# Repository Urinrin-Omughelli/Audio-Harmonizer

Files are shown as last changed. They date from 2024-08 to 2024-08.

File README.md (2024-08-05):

# Audio Harmonizer 
# 1.	Executive Summary
The Audio Harmonizer is a product that will revolutionize solo performances by introducing an affordable and easy to use system. Users can generate or build a series of harmonies through a mobile application which is used alongside a microphone and harmony generator to output multiple harmonies through a speaker in real time. The product utilizes signal manipulation to create harmonies from the user’s own voice. By combining converters, microcontrollers, and a mobile application, our team will create a system that produces a choir effect that can only be replicated by multiple pre-recorded voices. The following sections walk through a high level overview of the system as well as information regarding its use, users, and impact.

# 2.	Introduction
The system will be composed of a blackbox with audio input and output that connects to a mobile application via bluetooth to generate harmonies in real time. The system will be capable of generating harmonies for a variety of chord progressions at any tempo as well as allowing composers to create their own harmonies on the mobile app. Users such as solo independent artists and those without the proper money or resources for proper equipment can use our application to create more complex art easily.

# 2.1. Background
With a rise in accessibility of producing and creating music, artists have been known to rise to stardom via free applications one can find on their phone such as Soundcloud, Tiktok, or Youtube. By creating technology that allows people to create music from their bedrooms, the music industry has transformed allowing those without the proper funding or resources a fair chance at success. Our team has come up with a product that will allow even the most inexperienced musicians to bring complexity and artistry to their work in a way that previously was far more exclusive.
The audio harmonizer is an application that creates a four part harmony in real time. By connecting the necessary equipment to your phone via bluetooth, the mobile app allows you to have control over what harmonies you wish to add or create from scratch. Simply connect a microphone to the input and a speaker to the output on the equipment, pick the mode of operation and either use the automated harmonies or create your own, choose the volume settings for each harmony, and set the speed of the song. Now, when you sing or play into the microphone, an output of up to four melodies will be heard as the lead melody is being played.
Existing plugins that create harmonies do exist, however, most of the harmonizers can create only two  or three harmonies. In addition the more complex harmonizers are very expensive, costing up to $250 to use outside of a two week free trial. The plugins also only work with digital audio workstations (DAW). Good quality DAW can cost anywhere from $60 - $1000, which could be another cost that a small up and coming musician cannot afford. By making an affordable four part harmonizer that also can exist as a stand alone application, we are ensuring that independent artists can use our product to compose, produce, and perform.

The Audio Harmonizer system comprises two major components, the mobile application and the harmony generator, as seen in Figure 2.1. The mobile application that allows the users to choose the harmonies and the tempo of the music. This information will be passed via bluetooth to the harmony generator.  
The harmony generator takes an analog audio input from a microphone, converts it to a digital signal, uses the information passed down via bluetooth to generate the correct harmonies, and converts the new digital signal to an analog output which can be played through an amplifier.

Figure 1.1. Manual Mode Input-Output Diagram


Figure 1.2. Automatic Mode Input-Output Diagram

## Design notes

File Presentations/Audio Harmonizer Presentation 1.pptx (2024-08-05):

## Audio Harmonizer

Urinrinoghene Lauretta Omughelli and Team

## Project Statement

Create a system that allows artists to create multiple harmonies in real time for performances.

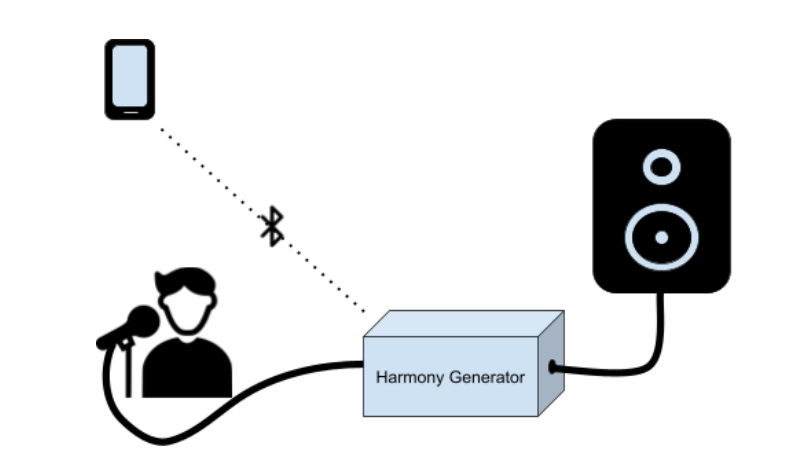
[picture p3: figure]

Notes: Jason

## Project Subsystems

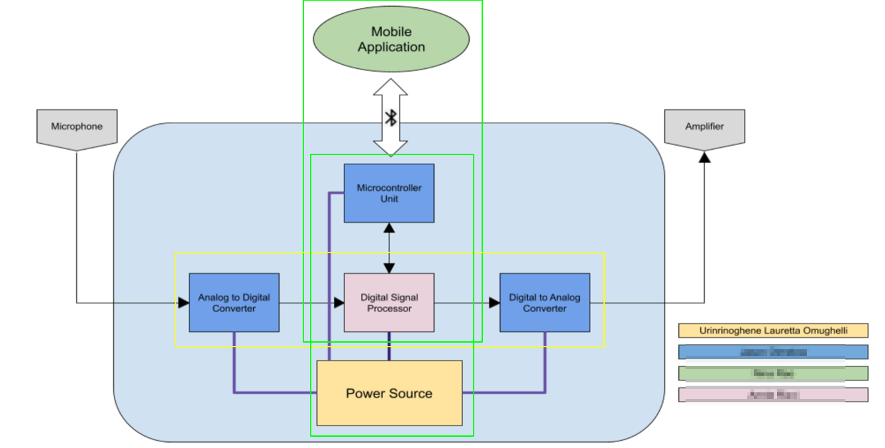
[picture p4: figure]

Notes: Nina:

## Major Changes

- DSP Hardware Switched to Real Time MCU
- No recording option due to time constraints
  - Originally an optional addition

## Project Current Timeline

- Integrating DSP Algorithms on to Real-Time MCU with Audio Booster Pack
- MCU and Android Application Bluetooth Communication
- Power PCB Order

## Subsystems

## Subsystem 1: Digital Signal Processor

Accomplishments Since 403 <20 hrs> | Ongoing progress/problems and plans until next presentation
Chose replacement Real-Time MCU for DSP subsystem | Running TI Sample Project Refactoring Sample Project for Harmonizing Algorithms Receive user input from MCU

## Digital Signal Processor

- MSP430 Real-Time MCU with BOOSTXL-AUDIO Pack
- TI Sample Project
  - Records for 3 seconds, plays for 3 seconds
  - Refactor to play and record in real time (with slight delay)
  - Insert algorithms from ECEN 403
- Set up code to take user input from MCU

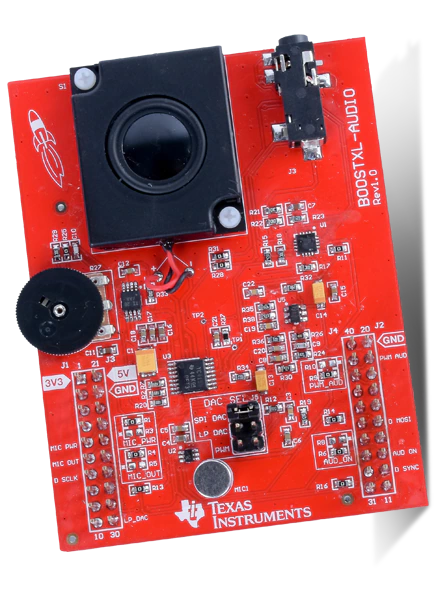
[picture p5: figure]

## Subsystem 2: Microcontroller Unit

Accomplishments Since 403 <30 hrs> | Ongoing progress/problems and plans
MCU Testing from last semester complete In process of Bluetooth integration | Communication with App via bluetooth Communication with Battery Fuel Gauge Communication with DSP

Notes: MCU will be relaying data to and fro the dsp/user interface via bluetooth. Telling the DSP what type of harmony the user wants, and then sending the digital to back to the app...

## Subsystem 3: Converters/Main Unit Schematic

Accomplishments Since 403 <5 Hrs> | Ongoing progress/problems and plans until next presentation
Have a physical PCB design from last semester that is now impractical for our use | Waiting for DSP hardware testing and selection to finish PCB manufacturing for DSP/MCU PCB unit

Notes: 24 bits is the optimal bitrate as 32 is unnecessary, 48kHz for HiFi audio, minimum is 40kHz for good audio quality

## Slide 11

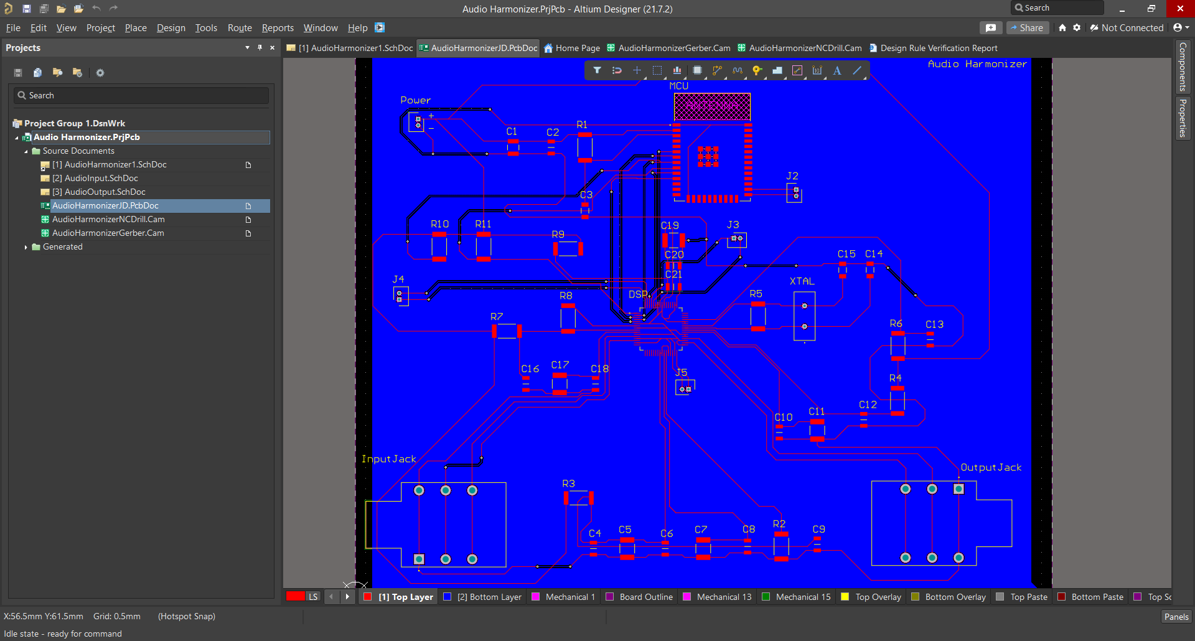
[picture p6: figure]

## Subsystem 4: Android Application

Accomplishments Since 403 <10 hrs> | Ongoing progress/problems and plans until next presentation
Application is ready to send data from automatic and manual mode Able to pair application to the ESP32 | Connect Android and ESP32 to send data

## Subsystem 5: Power Supply Urinrinoghene Lauretta Omughelli

Accomplishments Since 403 <60 hrs> | Ongoing progress/problems and plans until next presentation
Designed battery charger, fuel gauge and converter IC breakout boards for perf board testing Test and validation Modified schematic to fix low/unstable output voltage Completed PCB design revision | I2C programming of fuel gauge IC Test PCB and check output voltage

## Power Supply Urinrinoghene Lauretta omughelli

What currently works (On Perf board)?
-Battery charger IC charges battery
-Converter input voltage correctly switches between charger IC and battery
-Constant current when battery is charging
What doesn’t work?
-Low/unstable output voltage at buck-boost converter
What is changing?
- 1 buck boost converter

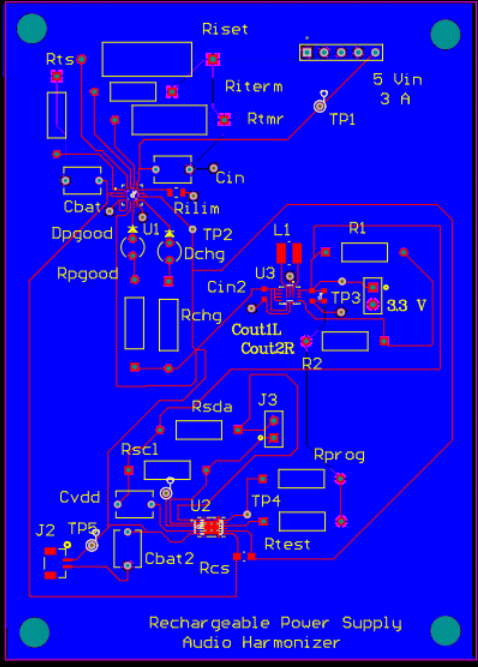
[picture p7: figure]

Updated PCB Design

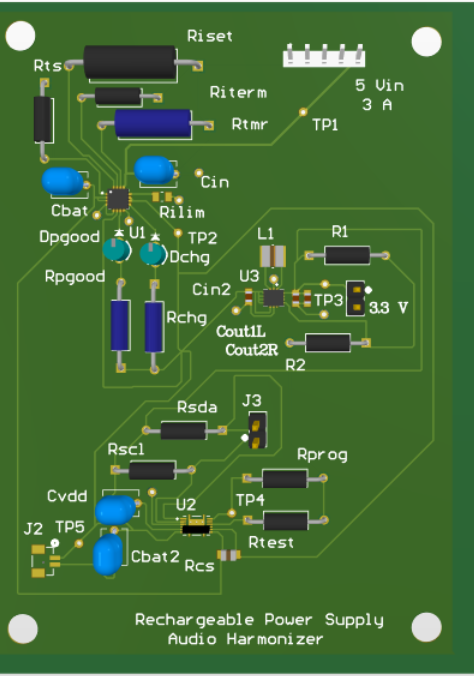
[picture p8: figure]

## Progress

## Parts Ordering Status

- All parts necessary for Power already ordered and received
- Power PCB Ordered
- MCU and DSP Ordered
- Order ADC/DAC that match TI DSP Launchpad
- Main PCB (MCU, DSP, ADC/DAC) will be ordered by next update

## Execution Plan

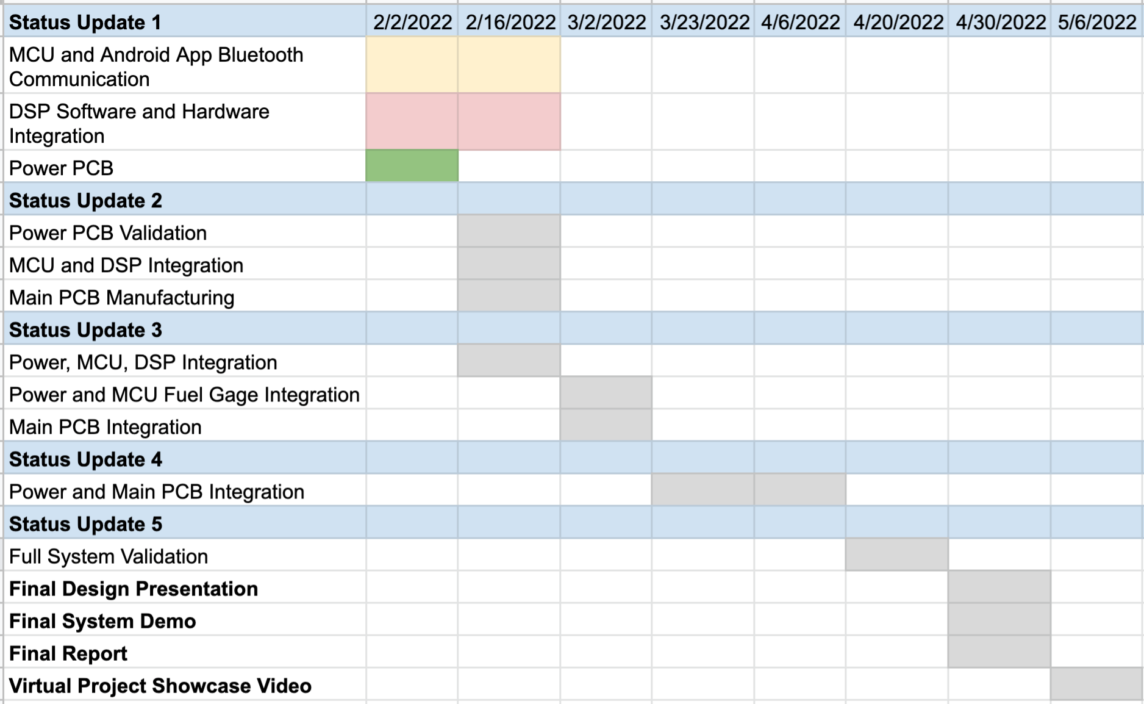
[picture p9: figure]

## Questions?

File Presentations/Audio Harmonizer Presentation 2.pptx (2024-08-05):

## Audio Harmonizer

Urinrinoghene Lauretta Omughelli and Team

## Project Statement

Create a system that allows artists to create multiple harmonies in real time for performances.


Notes: Jason

## Project Subsystems


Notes: Nina:

## Project Current Timeline

- Integrating DSP Algorithms on to Real-Time MCU
- MCU and Android Application Bluetooth Communication Complete
- Fuel Gauge Integration in Progress

## Subsystems

## Completed Subsystems

- Android Application
- Power Supply
- MCU

## Subsystem 1: Digital Signal Processor

Accomplishments Since 403 <30 hrs> | Ongoing progress/problems and plans until next presentation
Connected with TI Support Sample Project Running Two different avenues available Codec Interrupt Code | Process audio in and Out in Real Time Integrate Harmonies Receive user input from MCU

## Digital Signal Processor

- Electric Guitar Capo Capstone Project
  - Codec Functions
  - Project Code Mimics Existing Algorithm
- TI Sample Project
  - Waiting for TI Support
- Set up code to take user input from MCU


## Subsystem 2: Microcontroller Unit

Accomplishments Since 403 <25 hrs> | Ongoing progress/problems and plans
MCU Testing from last semester complete Communication with App via bluetooth Working on I2C communication with Battery Fuel Gauge | Communication with DSP

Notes: MCU will be relaying data to and fro the dsp/user interface via bluetooth. Telling the DSP what type of harmony the user wants, and then sending the digital to back to the app...

## Automatic Mode

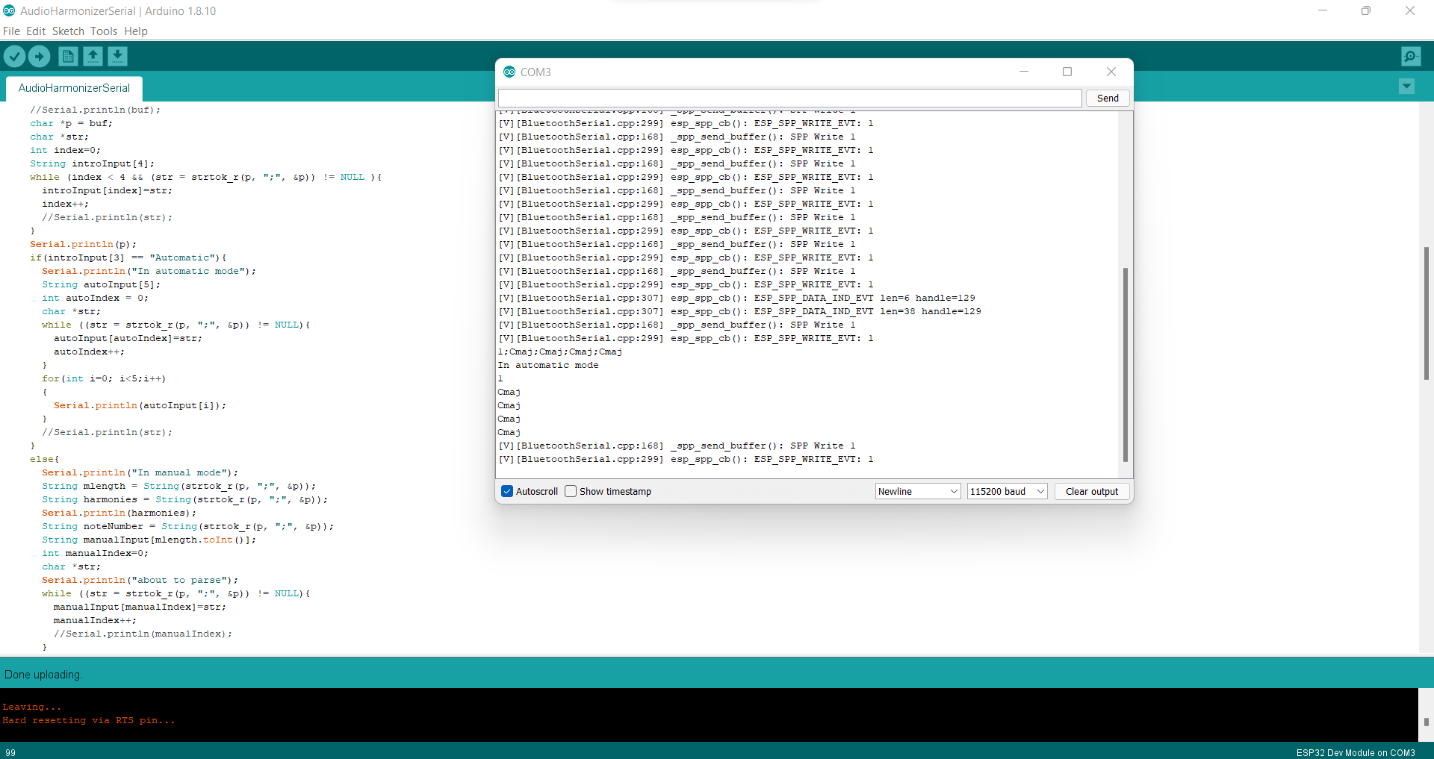
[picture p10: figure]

## Manual Mode

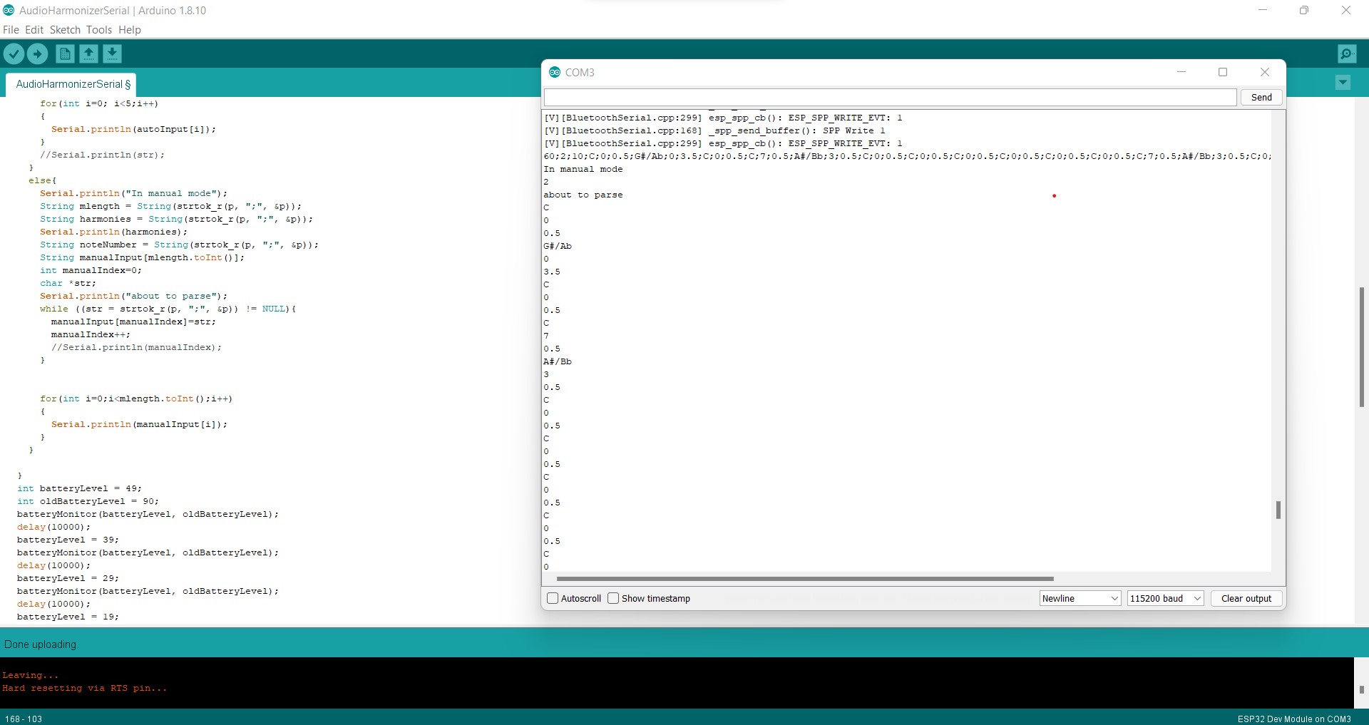
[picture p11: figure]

## Subsystem 3: Converters/Main Unit Schematic

Accomplishments Since 403 <0 Hrs> | Ongoing progress/problems and plans until next presentation
Have a physical PCB design from last semester that is now impractical for our use | Waiting for DSP hardware testing and selection to finish PCB manufacturing for DSP/MCU PCB unit

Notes: 24 bits is the optimal bitrate as 32 is unnecessary, 48kHz for HiFi audio, minimum is 40kHz for good audio quality

## Subsystem 4: Android Application

Accomplishments Since Last Presentation <25 hrs> | Ongoing progress/problems and plans until next presentation
Working bluetooth communication between ESP32 and Android App Interpret Data from app for the DSP Fixed styling issues | Display battery levels on the app

## Subsystem 5: Power Supply Urinrinoghene Lauretta Omughelli

Accomplishments Since Our Last Presentation <12 hrs> | Ongoing progress/problems and plans until next presentation
Ordered and Received PCB Worked on fuel gauge I2C programming in preparation for Integrating with MCU subsystem | PCB assembly, test, and validate 3.3 V at the output of the converter Test I2C communication with ESP 32

## Fuel Gauge Reading

- Arduino Library for BQ27411
  - Should work with BQ27441
- Arduino Code written to read I2C data for:
  - State of charge
  - Voltage
  - Current
- Re-test once parts are completely soldered

Lauretta & Annie

## Bluetooth Communication

- MCU and Android App Connect via Bluetooth
- Android App able to send user inputs as string
- MCU Arduino Code able to receive and interpret user input into corresponding variables for manual and automatic modes

Jason & Nina

## Progress

## Parts Ordering Status

- Main PCB needs to be designed and ordered

## Execution Plan

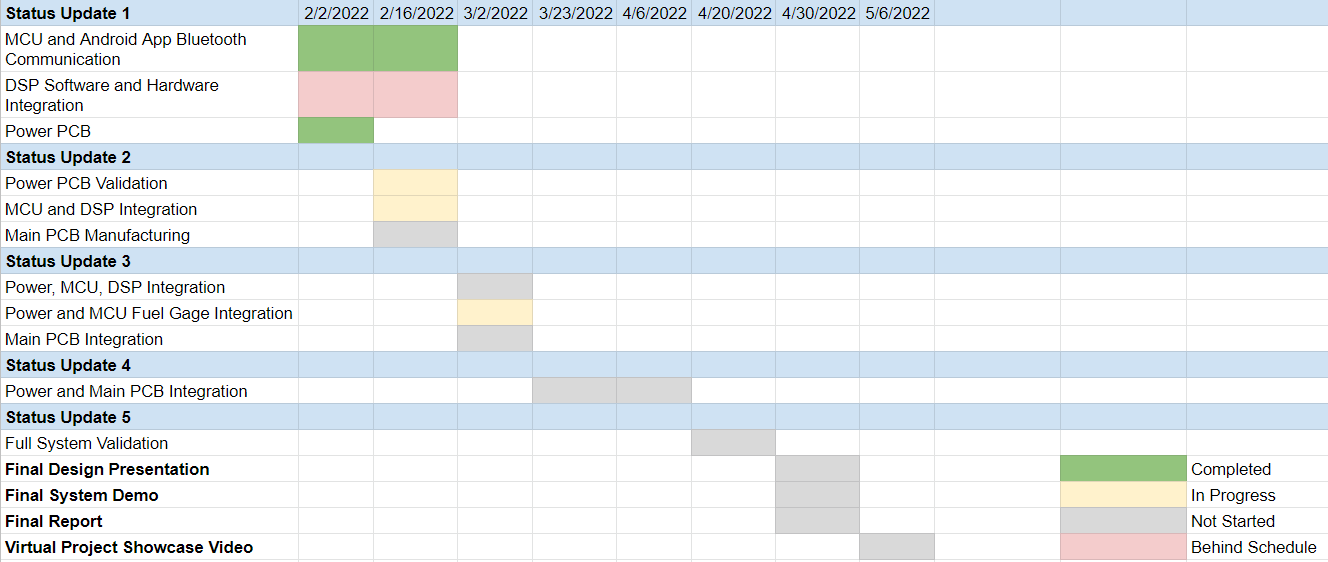
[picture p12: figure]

## Questions?

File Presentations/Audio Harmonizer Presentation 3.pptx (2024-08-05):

## Audio Harmonizer

Urinrinoghene Lauretta Omughelli and Team

## Project Statement

Create a system that allows artists to create multiple harmonies in real time for performances.


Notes: Jason

## Project Subsystems


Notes: Nina:

## Project Current Timeline

- Integrating DSP Algorithms on to Real-Time MCU
- MCU and Android Application Bluetooth Communication Complete
- Fuel Gauge Integration in Progress
- Main PCB Design in Progress
- Power Supply PCB Reordered

## Subsystem 1: Digital Signal Processor

Accomplishments Since Last Presentation <45 hrs> | Ongoing progress/problems and plans until next presentation
Met with TI Support Refactored project | Complete refactoring Integrate Harmonies Receive user input from MCU

## Digital Signal Processor

- 2 DMA Channels taking Audio input in ping-pong format
- Timer set to 20kHz for ADC and DAC input/output
- Close to completing continuous audio record and playback
- Meeting with TI Support set for tomorrow


## Microcontroller Unit Main Unit Schematic/PCB

Accomplishments Since Last Presentation <5 hrs> | Ongoing progress/problems and plans
MCU Testing from last semester complete Communication with App via bluetooth working fully | Communication with DSP Working on I2C communication with Battery Fuel Gauge

Accomplishments Since Last Presentation <15 Hrs> | Ongoing progress/problems and plans until next presentation
Soldered most of old design PCB | Will be attempting redesign with new MSP430 chip for audio in/out

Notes: MCU will be relaying data to and fro the dsp/user interface via bluetooth. Telling the DSP what type of harmony the user wants, and then sending the digital to back to the app...

## PCB Design

- Need to add missing capacitors
- Likely will redesign with MSP430

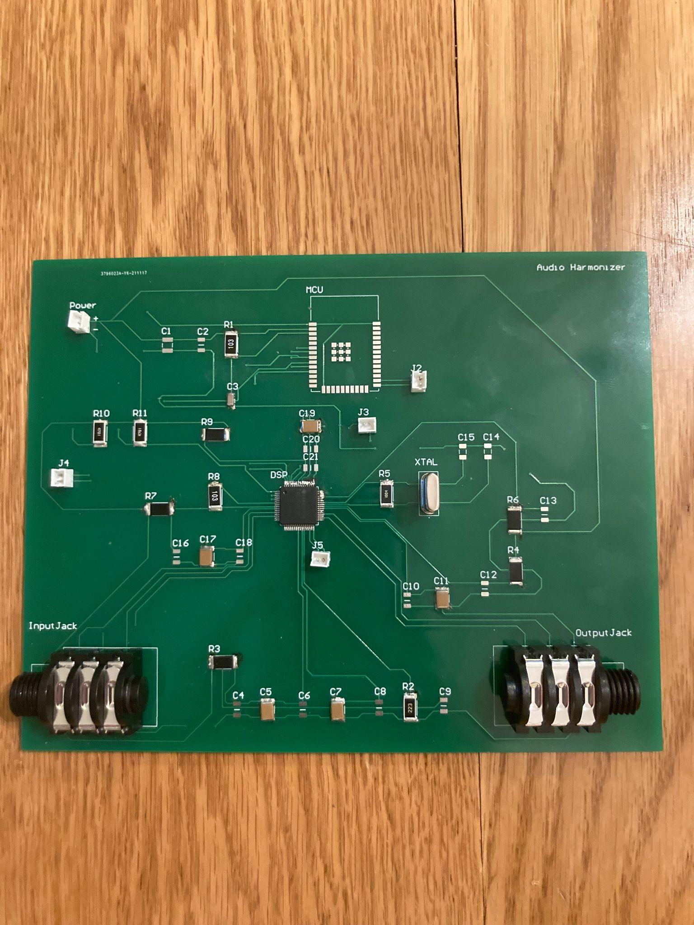
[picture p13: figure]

## Power Supply and Integration with MCU I2C Communication

Accomplishments Since Our Last Presentation <10 hrs> | Ongoing progress/problems and plans until next presentation
Tested PCB functionality Fuel gauge I2C programming for Integrating with MCU subsystem | PCB short circuit issue due to clearance rule violation being diabled in Altium Issue resolved and PCB reordered Test I2C communication with ESP 32

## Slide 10

Power Supply PCB

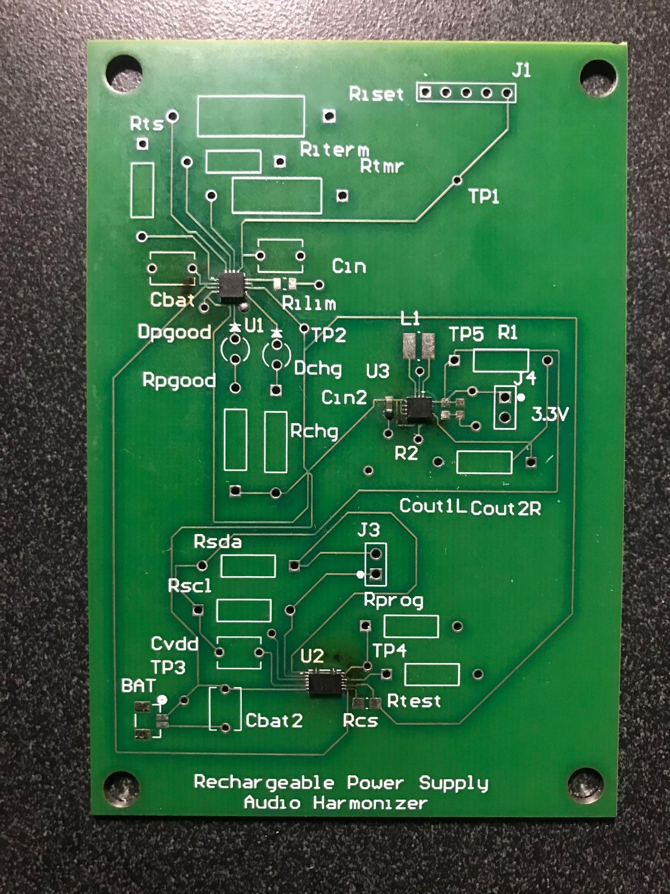
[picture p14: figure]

## Fuel Gauge Reading

- Arduino Library for BQ27411
  - Should work with BQ27441
- Arduino Code written to read I2C data for:
  - State of charge
  - Voltage
  - Current
- Re-test once parts are completely soldered

Lauretta & Annie

## Bluetooth Communication

- MCU and Android App Connect via Bluetooth
- Android App able to send user inputs as string
- MCU Arduino Code able to receive and interpret user input into corresponding variables for manual and automatic modes
- Android App is able to receive battery level from the MCU and display it accordingly

Jason & Nina

## Parts Ordering Status

- Main PCB needs to be ordered

## Progress

## Execution Plan

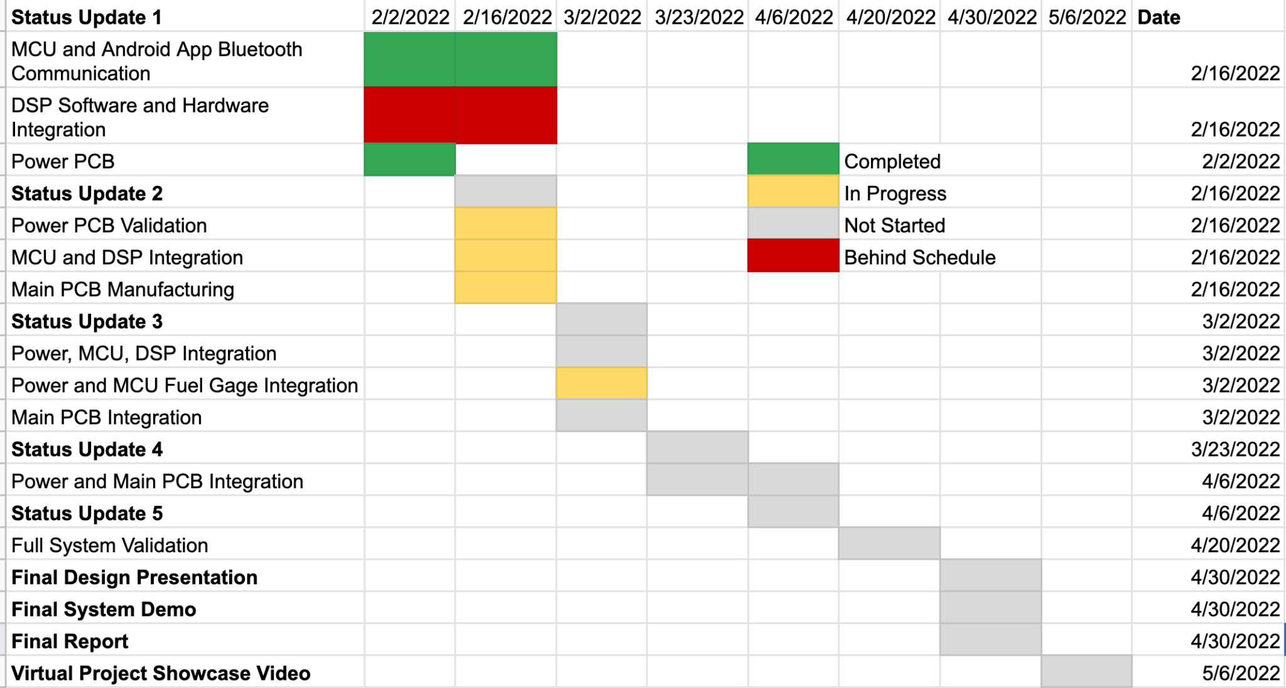
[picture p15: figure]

## Questions?

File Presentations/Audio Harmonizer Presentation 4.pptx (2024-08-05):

## Audio Harmonizer

Urinrinoghene Lauretta Omughelli and Team

## Project Statement

Create a system that allows artists to create multiple harmonies in real time for performances.


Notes: Jason

## Project Subsystems


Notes: Nina:

## Project Current Timeline

- Real-Time Audio Functioning
- MCU and Android Application Bluetooth Communication Integrated and Validated
- Fuel Gage Integrated (Not Validated)
- MCU and DSP I2C Communication Integrated and Validated
- Power Supply Integrated (Not Validated)

## Digital Signal Processor

Accomplishments Since Last Presentation <35 hrs> | Ongoing progress/problems and plans until next presentation
MSP430 Launchpad and ADC/DAC integration complete Audio working in Real-Time I2C Communication with MCU Integrated and Validated | Use IQMATHLIB for Hamonizing Algorithm and FFTs in MSP430

## I2C MCU and DSP Integration

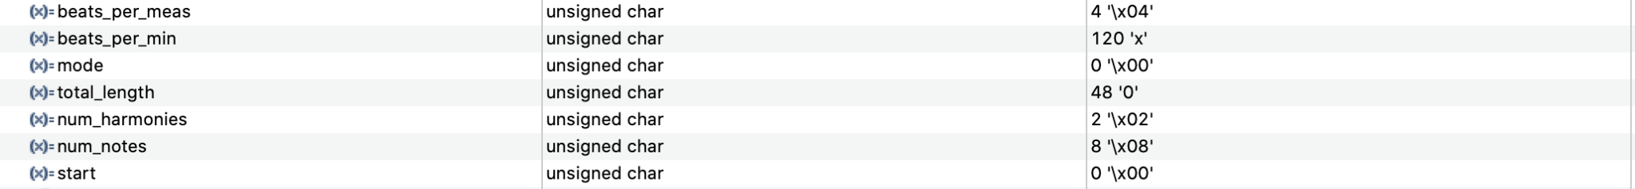
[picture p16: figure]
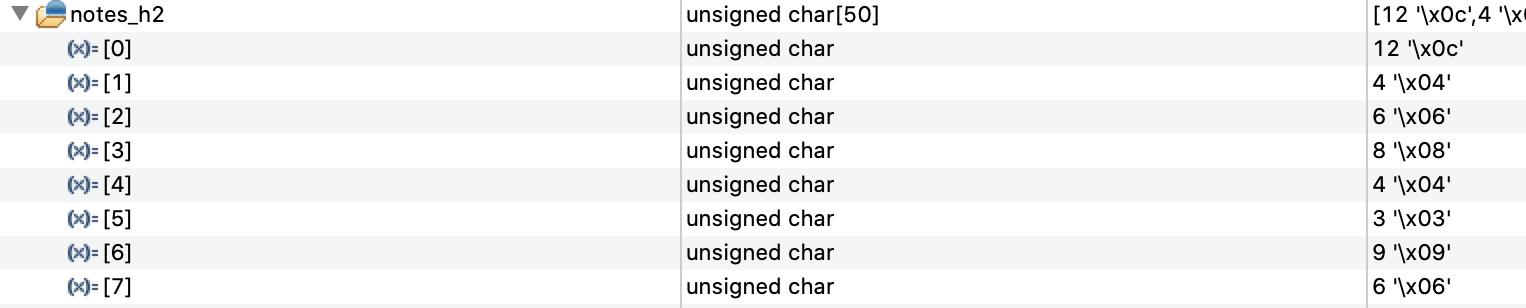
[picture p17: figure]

## Microcontroller Unit Main Unit Schematic/PCB

Accomplishments Since Last Presentation <~ hrs> | Ongoing progress/problems and plans
Integrated With all Other Systems

Accomplishments Since Last Presentation <30 Hrs> | Ongoing progress/problems and plans until next presentation
PCB and Parts Ordered | Solder and Test

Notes: MCU will be relaying data to and fro the dsp/user interface via bluetooth. Telling the DSP what type of harmony the user wants, and then sending the digital to back to the app...

## Schematics

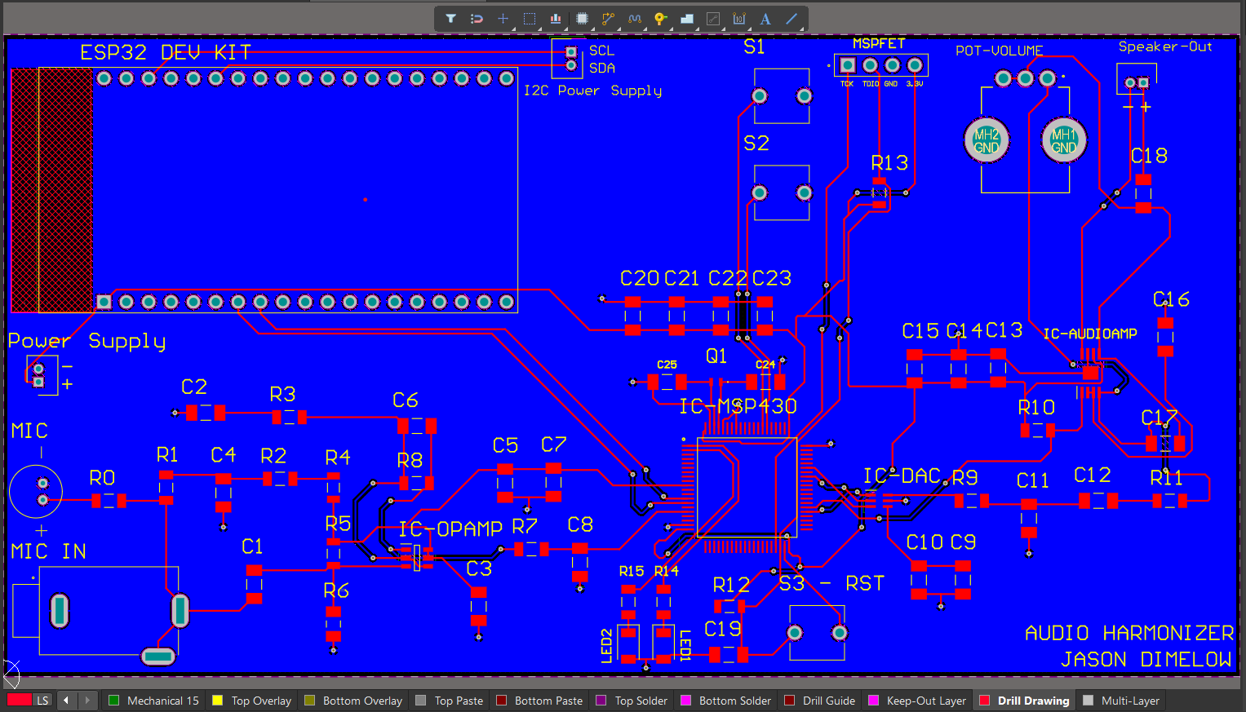
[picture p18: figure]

## Power Supply and Integration with MCU I2C Communication

Accomplishments Since Our Last Presentation <20 hrs> | Ongoing progress/problems and plans until next presentation
Tested PCB functionality Tested charger IC Fixed output voltage issue I2C communication between fuel gauge and MCU complete (reads state of charge, battery voltage, and capacitance) | Validate state of charge (%) reading of fuel gauge

## Fuel Gauge Integration

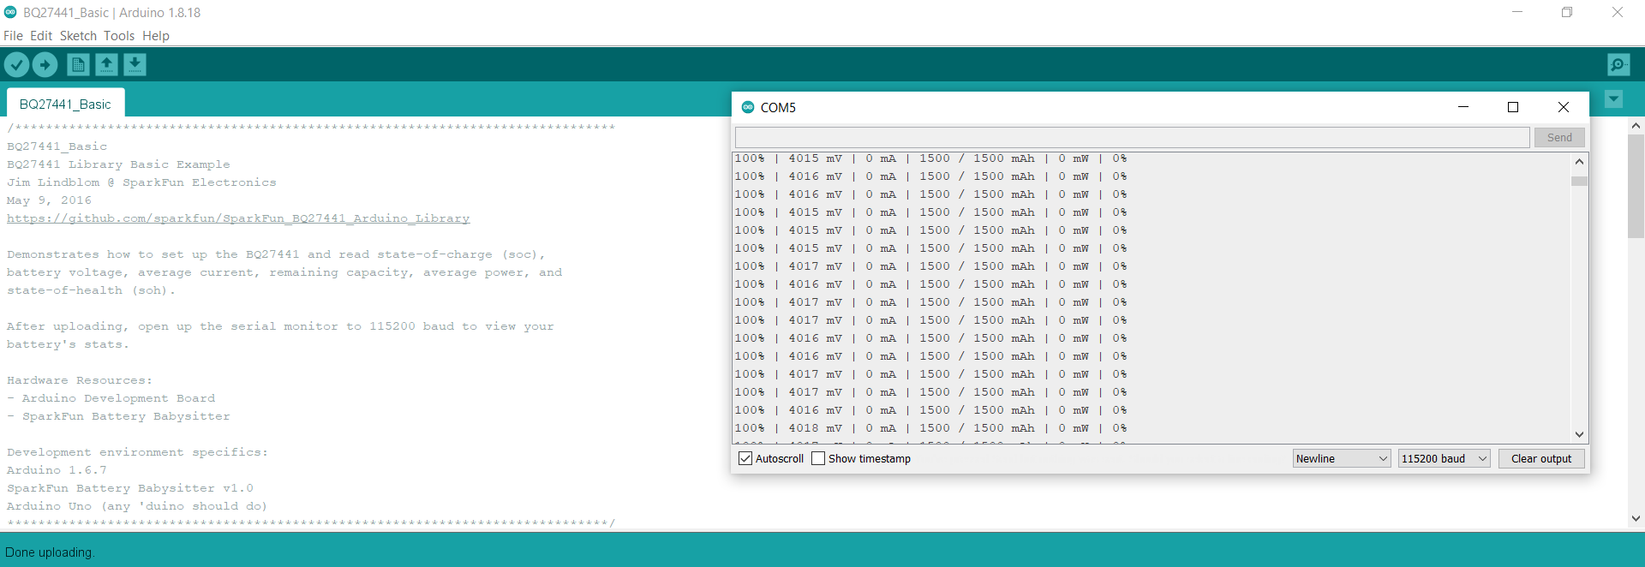
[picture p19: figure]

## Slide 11

Power Supply Validation

Dchg LED is low impedance when battery is disconnected

Dchg LED is high Impedance when battery is connected

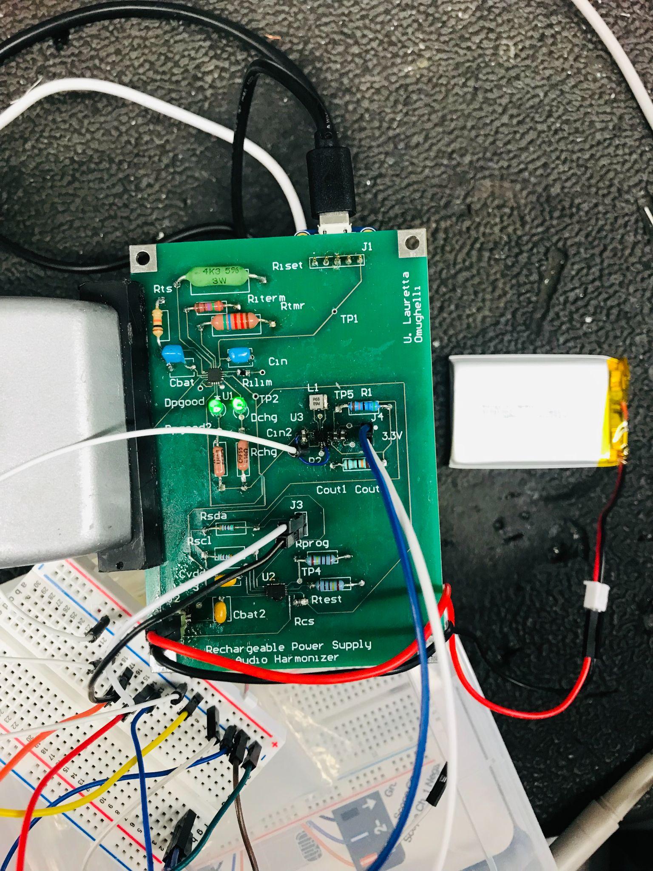
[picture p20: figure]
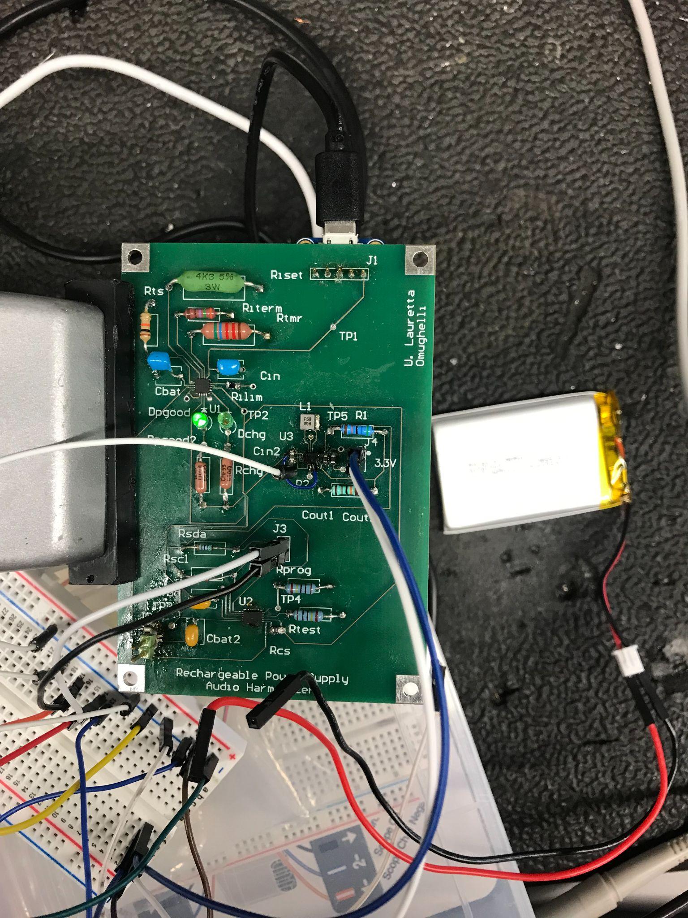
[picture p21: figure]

Shows that battery is disconnected/not charging

Shows that battery is charging

-LED on the left is always on to indicate that a valid input source is received

## Power Supply Waveform

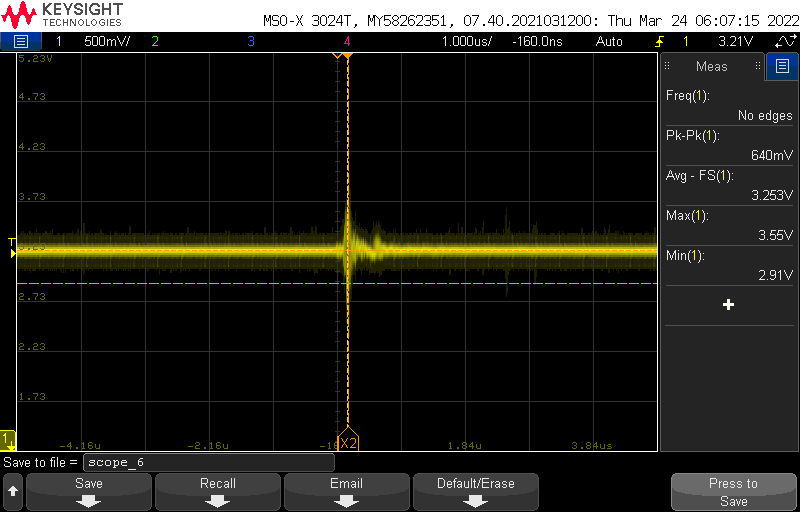
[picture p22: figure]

-Output voltage varies between 3.25-3.36V

## Power Supply Integration

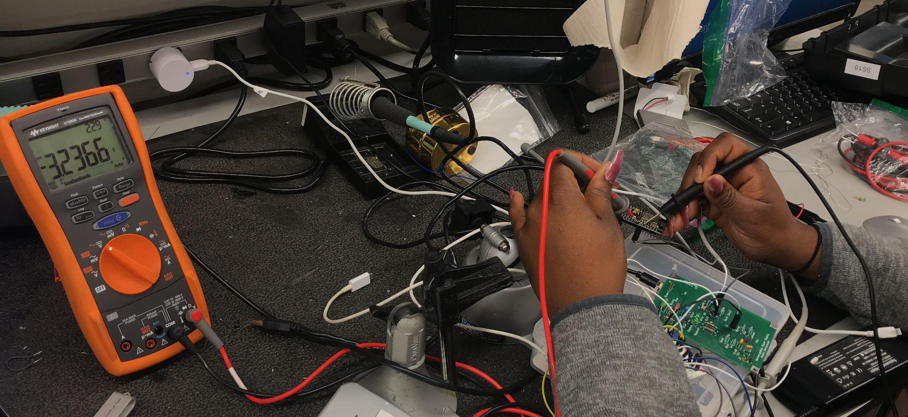
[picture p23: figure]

## Android App

Accomplishments Since Last Presentation <20 hrs> | Ongoing progress/problems and plans until next presentation
Error Handling Worked on Styling | Continue validating and integrating with full system

## Before & After

Bluetooth Page

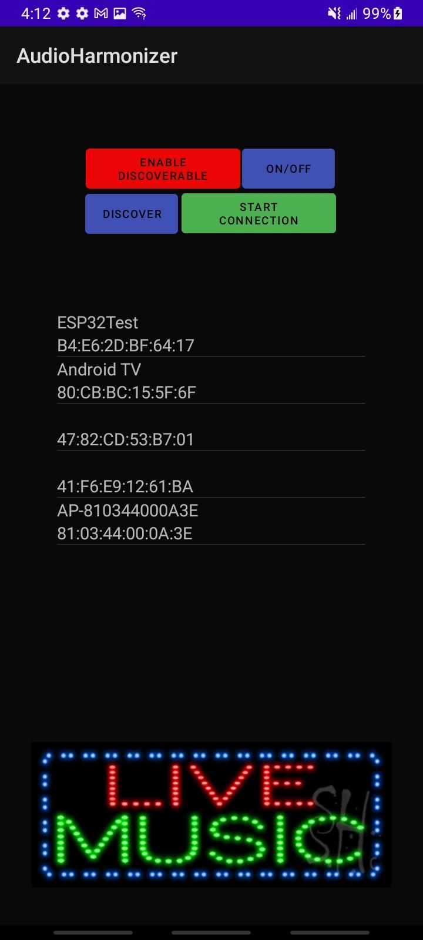
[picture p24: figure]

Initial Input Page

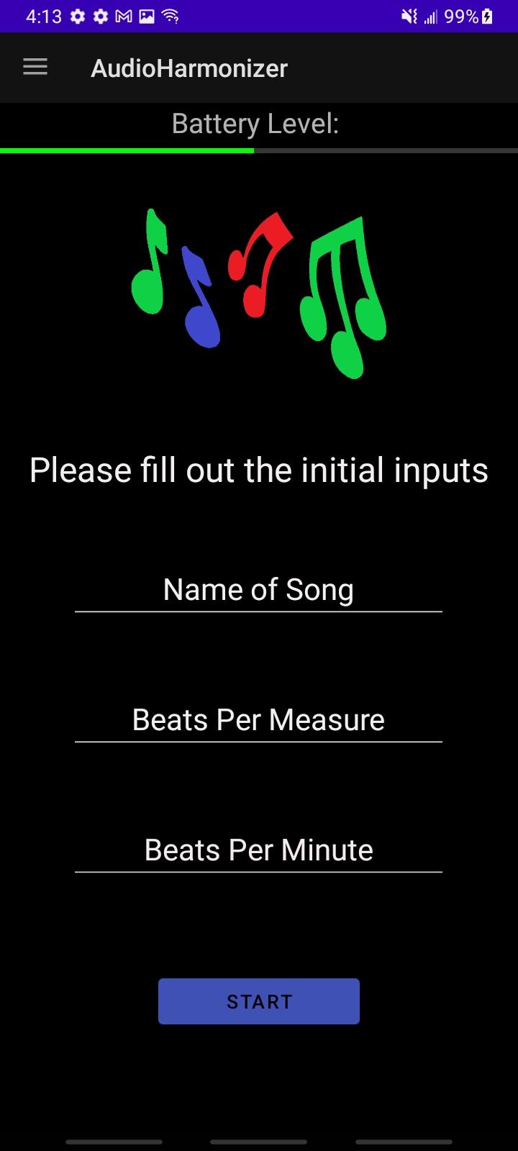
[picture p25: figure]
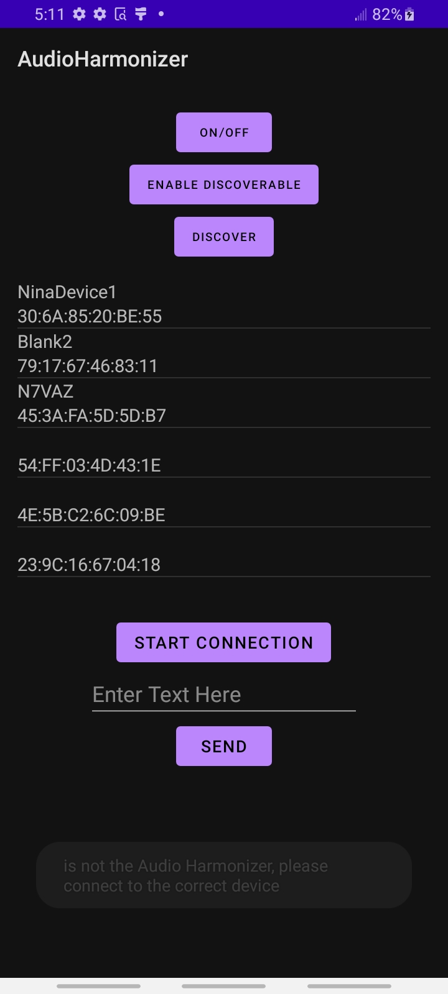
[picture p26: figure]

## Before & After


Automatic Page


Start Singing Page


## Progress

## Execution Plan


## Questions?

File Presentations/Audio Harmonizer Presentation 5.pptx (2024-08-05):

## Audio Harmonizer

Urinrinoghene Lauretta Omughelli and Team

## Project Statement

Create a system that allows artists to create multiple harmonies in real time for performances.


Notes: Jason

## Project Subsystems


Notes: Nina:

## Project Current Timeline

- Real-Time Audio Functioning
- MCU and Android Application Bluetooth Communication Integrated and Validated
- MCU and DSP I2C Communication Integrated and Validated
- Power Supply Integrated and Validated

## Digital Signal Processor

Accomplishments Since Last Presentation <18 hrs> | Ongoing progress/problems and plans until next presentation
Integrated IQMATHLIB into MSP430 Project Refactored parts of algorithm program into Code Composer Studio | Finish integrating algorithms and validate (non-real time version) Reattempt algorithm with complex DSK Kit for real-time functionality*

## Microcontroller Unit Main Unit Schematic/PCB

Accomplishments Since Last Presentation <3 hrs> | Ongoing progress/problems and plans
Seamless communication between Fuel Gauge, MCU, and Android App

Accomplishments Since Last Presentation <25 Hrs> | Ongoing progress/problems and plans until next presentation
Schematic Completed and Ordered | MSP430 Flash Hardware Solder parts

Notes: MCU will be relaying data to and fro the dsp/user interface via bluetooth. Telling the DSP what type of harmony the user wants, and then sending the digital to back to the app...

## Schematics


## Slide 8


## Power Supply Integration with MCU and Android App

Accomplishments Since Our Last Presentation <20 hrs> | Ongoing progress/problems and plans until next presentation
Successfully Integrated power supply with DSP (MSP430) and MCU (ESP32) Successfully Integrated fuel gauge with MCU/App | Validate battery percentage on App Output voltage starts at 2.6 V before reaching 3.3 V- Use linear regulator to fix 2.6 V output

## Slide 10

Power Supply Output Voltage Validation with DSP and MCU


## Android App

Accomplishments Since Last Presentation <20 hrs> | Ongoing progress/problems and plans until next presentation
Implemented new method for receiving battery level | Android App is complete

## Progress

## Execution Plan


## Questions?

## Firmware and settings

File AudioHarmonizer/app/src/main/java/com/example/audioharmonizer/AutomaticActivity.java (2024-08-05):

package com.example.audioharmonizer;

import androidx.annotation.NonNull;
import androidx.annotation.RequiresApi;
import androidx.appcompat.app.ActionBarDrawerToggle;
import androidx.appcompat.app.AppCompatActivity;
import androidx.drawerlayout.widget.DrawerLayout;

import android.Manifest;
import android.bluetooth.BluetoothAdapter;
import android.bluetooth.BluetoothDevice;
import android.bluetooth.BluetoothSocket;
import android.content.BroadcastReceiver;
import android.content.Context;
import android.content.Intent;
import android.content.IntentFilter;
import android.content.pm.PackageManager;
import android.content.pm.ResolveInfo;
import android.content.res.ColorStateList;
import android.graphics.Color;
import android.net.Uri;
import android.os.Build;
import android.os.Bundle;
import android.os.Environment;
import android.os.Handler;
import android.util.Log;
import android.view.MenuItem;
import android.view.View;
import android.widget.AdapterView;
import android.widget.ArrayAdapter;
import android.widget.Button;
import android.widget.EditText;
import android.widget.ListView;
import android.widget.ProgressBar;
import android.widget.Spinner;
import android.widget.Toast;

import com.google.android.material.navigation.NavigationView;

import java.io.File;
import java.io.IOException;
import java.io.InputStream;
import java.nio.charset.Charset;
import java.util.ArrayList;
import java.util.List;
import java.util.UUID;

public class AutomaticActivity extends AppCompatActivity implements NavigationView.OnNavigationItemSelectedListener{

    Button automatic_finish_button;//send button

    private static final String TAG = "AutomaticActivity";

    BluetoothDevice mBTDevice;
    BluetoothAdapter mBlueAdapter;
    //public ArrayList<BluetoothDevice> mBTDevices = new ArrayList<>();

    public DrawerLayout drawerLayout_automatic;
    public ActionBarDrawerToggle actionBarDrawerToggle_automatic;
    private NavigationView navigationView;
    public String delim = ";";

    private Handler handler = new Handler();
    int batteryLevel = 0;
    ProgressBar progress;


    @Override
    protected void onCreate(Bundle savedInstanceState) {
        super.onCreate(savedInstanceState);
        setContentView(R.layout.activity_automatic);

        final GlobalClass globalVariable = (GlobalClass) getApplicationContext();

        //**********************************bluetooth***************************************


        mBlueAdapter = BluetoothAdapter.getDefaultAdapter();
        if(!mBlueAdapter.isEnabled()){
            showToast("You must turn bluetooth back on");
            Intent intent = new Intent(AutomaticActivity.this, Bluetooth2Activity.class);
            startActivity(intent);
        }


        //**********************************bluetooth***************************************



        //**********************NavBar Functionality START**********************************
        drawerLayout_automatic = findViewById(R.id.my_drawer_layout_automatic);
        actionBarDrawerToggle_automatic = new ActionBarDrawerToggle(this, drawerLayout_automatic, R.string.nav_open, R.string.nav_close);

        // pass the Open and Close toggle for the drawer layout listener
        // to toggle the button
        drawerLayout_automatic.addDrawerListener(actionBarDrawerToggle_automatic);
        actionBarDrawerToggle_automatic.syncState();

        // to make the Navigation drawer icon always appear on the action bar
        getSupportActionBar().setDisplayHomeAsUpEnabled(true);

        navigationView = findViewById(R.id.navigationview_id_automatic);
        navigationView.setNavigationItemSelectedListener(this);

        MenuItem menuItem = navigationView.getMenu().getItem(3).setChecked(true);
        onNavigationItemSelected(menuItem);
        //**********************NavBar Functionality END**********************************


        Spinner cp_spinner = (Spinner) findViewById(R.id.cp_spinner);
        Spinner cp_spinner2 = (Spinner) findViewById(R.id.cp_spinner2);
        Spinner cp_spinner3 = (Spinner) findViewById(R.id.cp_spinner3);
        Spinner cp_spinner4 = (Spinner) findViewById(R.id.cp_spinner4);

        Spinner noh_spinner = (Spinner) findViewById(R.id.noh_spinner);


        //***************************Chord Progression Spinners***************************************

        ArrayAdapter<String> myAdapter = new ArrayAdapter<String>(AutomaticActivity.this,
                android.R.layout.simple_list_item_1, getResources().getStringArray(R.array.chord_progressions));
        myAdapter.setDropDownViewResource(android.R.layout.simple_spinner_dropdown_item);
        cp_spinner.setAdapter(myAdapter);

        ArrayAdapter<String> myAdapter2 = new ArrayAdapter<String>(AutomaticActivity.this,
                android.R.layout.simple_list_item_1, getResources().getStringArray(R.array.chord_progressions));
        myAdapter2.setDropDownViewResource(android.R.layout.simple_spinner_dropdown_item);
        cp_spinner2.setAdapter(myAdapter2);

        ArrayAdapter<String> myAdapter3 = new ArrayAdapter<String>(AutomaticActivity.this,
                android.R.layout.simple_list_item_1, getResources().getStringArray(R.array.chord_progressions));
        myAdapter3.setDropDownViewResource(android.R.layout.simple_spinner_dropdown_item);
        cp_spinner3.setAdapter(myAdapter3);

        ArrayAdapter<String> myAdapter4 = new ArrayAdapter<String>(AutomaticActivity.this,
                android.R.layout.simple_list_item_1, getResources().getStringArray(R.array.chord_progressions));
        myAdapter4.setDropDownViewResource(android.R.layout.simple_spinner_dropdown_item);
        cp_spinner4.setAdapter(myAdapter4);
        //*********************************************************************************************************

        ArrayAdapter<String> myHarmonyAdapter = new ArrayAdapter<String>(AutomaticActivity.this,
                android.R.layout.simple_list_item_1, getResources().getStringArray(R.array.number_of_harmonies));
        myHarmonyAdapter.setDropDownViewResource(android.R.layout.simple_spinner_dropdown_item);
        noh_spinner.setAdapter(myHarmonyAdapter);

        //**************************Battery Level Updates**********************************************************

        progress = (ProgressBar) findViewById(R.id.simpleProgressBar);
        if(Integer.parseInt(GlobalClass.getInstance().getBatteryLevel())  < 21){
            progress.setProgressTintList(ColorStateList.valueOf(Color.RED));
        } else{
            progress.setProgressTintList(ColorStateList.valueOf(Color.GREEN));
        }
        progress.setProgress(Integer.parseInt(GlobalClass.getInstance().getBatteryLevel()));
        updateBattery();



        automatic_finish_button = (Button)findViewById(R.id.automatic_finish_button);
        automatic_finish_button.setOnClickListener(new View.OnClickListener() {
            public void onClick(View v)
            {
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

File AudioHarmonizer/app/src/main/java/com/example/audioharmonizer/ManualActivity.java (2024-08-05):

package com.example.audioharmonizer;

import androidx.annotation.NonNull;
import androidx.appcompat.app.ActionBarDrawerToggle;
import androidx.appcompat.app.AppCompatActivity;
import androidx.drawerlayout.widget.DrawerLayout;

import android.bluetooth.BluetoothAdapter;
import android.bluetooth.BluetoothSocket;
import android.content.Intent;
import android.content.res.ColorStateList;
import android.content.res.Resources;
import android.graphics.Color;
import android.os.Bundle;
import android.os.Handler;
import android.view.Gravity;
import android.view.MenuItem;
import android.view.View;
import android.view.ViewGroup;
import android.widget.ArrayAdapter;
import android.widget.Button;
import android.widget.EditText;
import android.widget.LinearLayout;
import android.widget.ProgressBar;
import android.widget.ScrollView;
import android.widget.Spinner;
import android.widget.TextView;
import android.widget.Toast;

import com.google.android.material.navigation.NavigationView;

import java.io.IOException;
import java.io.InputStream;
import java.nio.charset.Charset;
import java.util.ArrayList;

public class ManualActivity extends AppCompatActivity implements NavigationView.OnNavigationItemSelectedListener {

    Button manual_finish_button, generate_new_button;
    private NavigationView navigationView;
    public DrawerLayout drawerLayout_manual;
    public ActionBarDrawerToggle actionBarDrawerToggle_manual;
    BluetoothAdapter mBlueAdapter;
    public int manualArrayLength;
    public String delim = ";";
    public int numberHarmonyToSend;
    public int numberNotesToSend;

    private Handler handler = new Handler();
    int batteryLevel = 0;
    ProgressBar progress;



    @Override
    protected void onCreate(Bundle savedInstanceState) {
        super.onCreate(savedInstanceState);
        setContentView(R.layout.activity_manual);

        final GlobalClass globalVariable = (GlobalClass) getApplicationContext();
        globalVariable.getManualArrayList().clear();

        initializeNavBar();

        //********************************bluetooth***********************************
        mBlueAdapter = BluetoothAdapter.getDefaultAdapter();
        if(!mBlueAdapter.isEnabled()){
            showToast("You must turn bluetooth back on");
            Intent intent = new Intent(ManualActivity.this, Bluetooth2Activity.class);
            startActivity(intent);
        }


        progress = (ProgressBar) findViewById(R.id.simpleProgressBar);
        if(Integer.parseInt(GlobalClass.getInstance().getBatteryLevel())  < 21){
            progress.setProgressTintList(ColorStateList.valueOf(Color.RED));
        } else{
            progress.setProgressTintList(ColorStateList.valueOf(Color.GREEN));
        }
        progress.setProgress(Integer.parseInt(GlobalClass.getInstance().getBatteryLevel()));
        updateBattery();

        EditText number_of_harmonies = (EditText) findViewById(R.id.number_of_harmonies);
        EditText notes_per_harmony = (EditText) findViewById(R.id.notes_per_harmony);

       // manual_finish_button.setEnabled(false);

        generate_new_button = (Button)findViewById(R.id.generate_new);
        LinearLayout myLayout = (LinearLayout) findViewById(R.id.linear_inside_scroll);
        //ScrollView myScrollview = findViewById(R.id.scrollView_manual);

        generate_new_button.setOnClickListener(new View.OnClickListener() {
            public void onClick(View v) {

                   // manual_finish_button.setEnabled(true);

                    if(Integer.parseInt(notes_per_harmony.getText().toString())>50){
                        showToast("You cannot add more than 50 notes");
                    }else if(Integer.parseInt(number_of_harmonies.getText().toString())>3){
                        showToast("You cannot add more than 3 harmonies");
                    }else {
                        //generate_new_button.setEnabled(false);
                        numberHarmonyToSend = Integer.parseInt(number_of_harmonies.getText().toString());


                        //creating the length array{
                        final ArrayList<String> lengthArray = new ArrayList<String>();
                        for (double i = 0.5; i <= Integer.parseInt(globalVariable.getBeatsPerMeasure()); i += 0.5) {
                            lengthArray.add(String.valueOf(i));
                        }

                        numberHarmonyToSend = Integer.parseInt(number_of_harmonies.getText().toString());
                        numberNotesToSend = Integer.parseInt(notes_per_harmony.getText().toString());


                        int NumberOfHarmonies = Integer.parseInt(number_of_harmonies.getText().toString());
                        int count = 1;
                        int k = 1;

                        manualArrayLength = numberHarmonyToSend * numberNotesToSend * 3;

                        while (NumberOfHarmonies != 0) {

                            String num = Integer.toString(count);
                            TextView HarmonyNumber = new TextView(ManualActivity.this);
                            HarmonyNumber.setText("Harmony " + num);
                            HarmonyNumber.setGravity(Gravity.HORIZONTAL_GRAVITY_MASK);
                            LinearLayout.LayoutParams tvHarmonyNumber = new LinearLayout.LayoutParams(LinearLayout.LayoutParams.WRAP_CONTENT, LinearLayout.LayoutParams.WRAP_CONTENT);
                            tvHarmonyNumber.setMargins(dpToPx(20), dpToPx(0), dpToPx(20), dpToPx(0));
                            HarmonyNumber.setPadding(dpToPx(0), dpToPx(0), dpToPx(0), dpToPx(0));
                            HarmonyNumber.setLayoutParams(tvHarmonyNumber);
                            myLayout.addView(HarmonyNumber);


                            TextView tvNote = new TextView(ManualActivity.this);
                            tvNote.setText("Note, Octave, and Length Blocks:");
                            tvNote.setGravity(Gravity.HORIZONTAL_GRAVITY_MASK);
                            LinearLayout.LayoutParams tvNoteLayout = new LinearLayout.LayoutParams(LinearLayout.LayoutParams.WRAP_CONTENT, LinearLayout.LayoutParams.WRAP_CONTENT);
                            tvNoteLayout.setMargins(dpToPx(20), dpToPx(10), dpToPx(20), dpToPx(0));
                            tvNote.setLayoutParams(tvNoteLayout);
                            //tvNote.setPadding(0, 0, 0, 0);
                            myLayout.addView(tvNote);
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

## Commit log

2024-08-05 Create Power Supply
2024-08-05 Create Main PCB
